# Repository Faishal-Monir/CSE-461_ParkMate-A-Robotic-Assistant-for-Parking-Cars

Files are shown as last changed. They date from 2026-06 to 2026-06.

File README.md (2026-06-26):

# ParkMate - A Robotic Assistant for Parking Cars

## CSE461: Introduction to Robotics [ FALL 2025 ]









ParkMate is a CSE461 robotics project that demonstrates a smart robotic parking assistant.  
The system detects vehicles, opens and closes gates automatically, monitors parking-slot availability, gives visual guidance, supports an EV charging slot, and logs parking status through a dashboard system.

<p align="center">
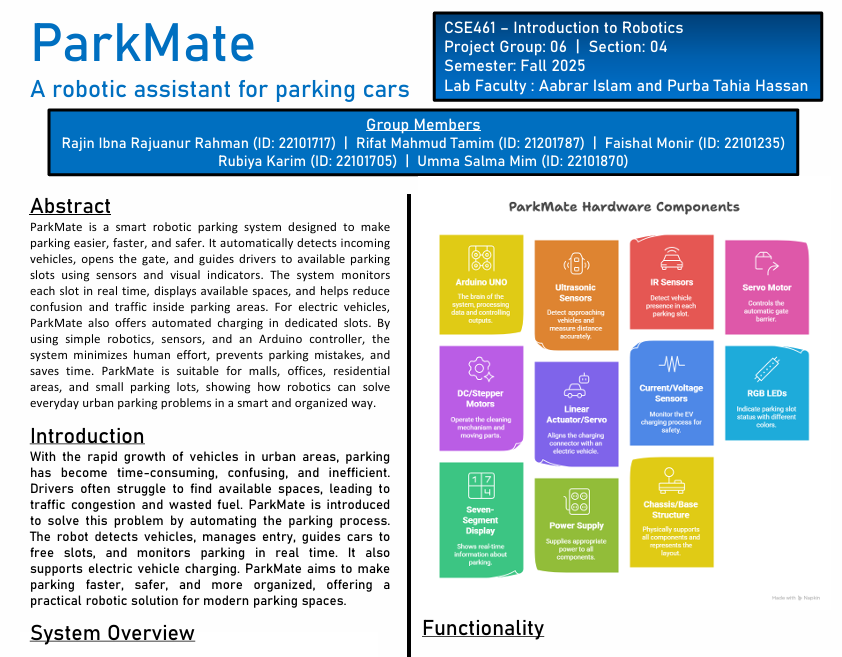
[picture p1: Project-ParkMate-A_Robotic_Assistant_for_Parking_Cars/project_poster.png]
ParkMate Project Poster
  
</p>

<p align="center">
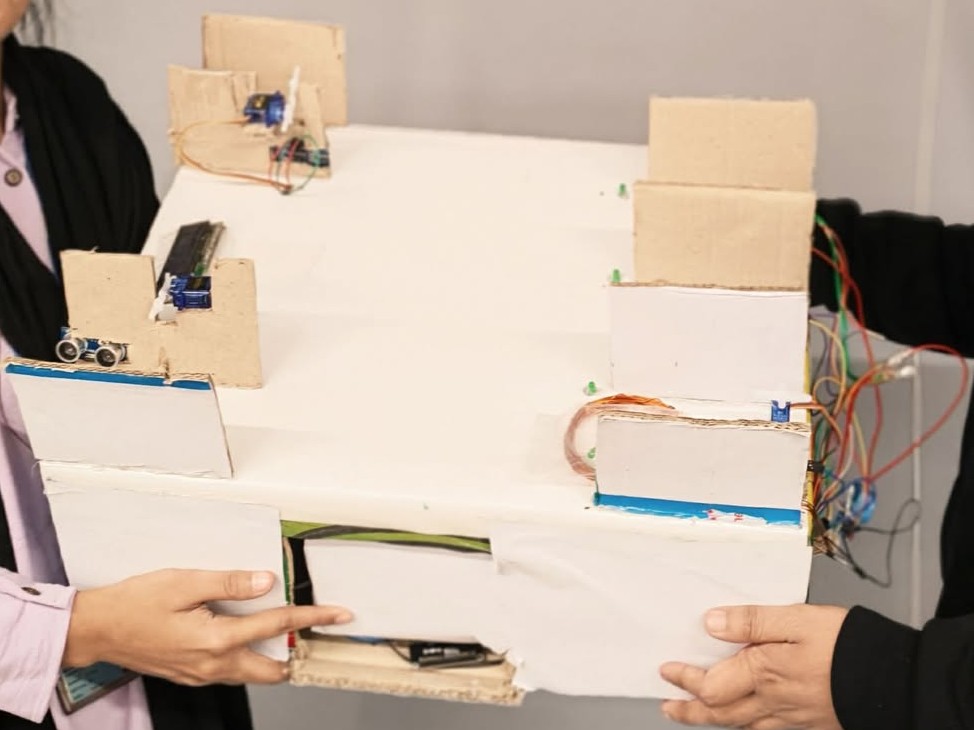
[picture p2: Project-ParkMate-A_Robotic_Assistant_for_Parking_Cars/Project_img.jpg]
ParkMate Hardware Prototype
  
  ParkMate Circuit Diagram
</p>

---

## Table of Contents

- [Repository Highlights](#repository-highlights)
- [Project: ParkMate](#project-parkmate)
- [Course Information](#course-information)
- [Project Overview](#project-overview)
- [System Architecture](#system-architecture)
- [Features](#features)
- [Hardware Components](#hardware-components)
- [Communication Protocols Used](#communication-protocols-used)
- [System Workflow](#system-workflow)
- [Pin / Connection Configuration](#pin--connection-configuration)
- [Required Arduino Libraries](#required-arduino-libraries)
- [Dashboard and Data Logging](#dashboard-and-data-logging)
- [Repository Structure](#repository-structure)
- [Project Files](#project-files)
- [Project Group Members](#project-group-members)
- [Future Work](#future-work)
- [License](#license)

---

## Repository Highlights

- Three-slot smart parking prototype built for **CSE461: Introduction to Robotics**
- Automatic vehicle detection at entry and exit gates using ultrasonic sensors
- Automatic gate opening and closing using servo motors
- Real-time parking-slot detection using IR sensors
- LED-based slot guidance for available and occupied parking spaces
- I2C LCD display for showing car count and available parking slots
- EV charging support for Slot 1 using a relay-based control system
- Automated dashboard/data logging support using ESP8266 and spreadsheet logging
- Slot-cleaning concept using servo motors and a DC motor
- Includes final report, project poster, prototype image, Fritzing circuit diagram, dashboard spreadsheet, and lab files

---

## Project: ParkMate

**ParkMate** is a robotic assistant for parking cars. It is designed to make parking easier, faster, safer, and more organized in small to medium parking areas.

The prototype uses an **Arduino UNO** as the main controller. Sensors detect incoming cars, outgoing cars, and slot occupancy. Based on the sensor readings, the system controls gates, LEDs, display output, EV charging status, and cleaning actuators. The project shows how robotics concepts such as sensing, decision-making, actuation, and automation can solve a real-world parking problem.

---

## Course Information

**Course:** CSE461: Introduction to Robotics  
**Offered:** Fall 2025  
**Pre-requisite:** CSE260, CSE341, CSE360  
**Semester:** Fall 2025  
**Section:** 04  
**Project Group:** 06  

This course introduces robotics by discussing basic laws, architectures, control systems, perceiving techniques, and communication. It also investigates kinematics, motor action, mechanical engineering issues, advanced communication protocols, and uses of AI in robotics.

---

## Project Overview

Parking has become a major problem in busy urban areas because the number of vehicles is increasing while parking space is limited. Drivers often waste time and fuel searching for an empty parking slot. Manual parking systems also depend heavily on human monitoring and do not always provide real-time slot information.

ParkMate solves this problem by automating the main parking tasks. The system detects a vehicle near the gate, opens the gate automatically, checks available slots, guides the driver using LEDs, updates the LCD display, and records parking information in a dashboard log. It also includes EV charging support for one slot and a simple automated slot-cleaning concept.

---

## System Architecture

ParkMate follows a simple robotics architecture with three main layers:

| Layer | Components | Function |
|---|---|---|
| Input Layer | HC-SR04 ultrasonic sensors, IR slot sensors | Detect cars at entry/exit gates and detect slot occupancy |
| Processing Layer | Arduino UNO, ESP8266 | Read sensor data, make decisions, control outputs, send dashboard data |
| Output Layer | Servo motors, DC motor, relay module, LEDs, LCD | Open/close gates, show slot status, control EV charging, display parking data |

---

## Features

- Automatic entry-gate detection and gate control
- Automatic exit-gate detection and gate control
- Three-slot parking availability monitoring
- IR sensor-based car detection for each slot
- LED guidance system for showing available or occupied slots
- LCD display showing total cars and free parking spaces
- Slot 1 EV charging support using a relay-controlled charging system
- ESP8266-based automated dashboard/data transfer concept
- Google Spreadsheet / Excel-based parking log support
- Cleaning mechanism using servo motors for Slot 1 and Slot 2
- DC motor-based cleaning mechanism for Slot 3
- Low-cost and modular prototype design

---

## Hardware Components

| Component | Quantity / Use | Purpose |
|---|---:|---|
| Arduino UNO | 1 | Main microcontroller for decision-making and control |
| ESP8266 | 1 | Sends parking data to the automated dashboard system |
| HC-SR04 Ultrasonic Sensor | 2 | Detects cars at entry and exit gates |
| IR Sensor Module | 3 | Detects whether each parking slot is occupied or empty |
| SG90 Servo Motor | 5 | Controls entry/exit gates and slot-cleaning mechanisms |
| DC Motor | 1 | Used for Slot 3 cleaning actuator |
| 5V Relay Module | 1+ | Controls EV charging / external load switching |
| 16x2 I2C LCD | 1 | Displays car count and available slots |
| RGB / Status LEDs | Multiple | Shows slot availability and system state |
| Resistors, Diode, Transistor | As required | Protects and controls circuit connections |
| Breadboard and Jumper Wires | As required | Builds and connects the prototype circuit |
| 5V / 12V DC Power Supply | 1 | Provides stable power for motors and modules |
| Acrylic / Plywood Base | 1 | Holds the parking-lot prototype structure |

---

## Communication Protocols Used

| Protocol / Method | Used For |
|---|---|
| Digital GPIO | Ultrasonic sensors, IR sensors, LEDs, relay control |
| PWM | Servo motor control and motor actuation |
| I2C | 16x2 LCD display communication |
| UART / Serial-style Communication | Arduino and ESP8266 data transfer concept |
| Wi-Fi / HTTP | ESP8266 dashboard and spreadsheet logging concept |
| Relay Switching | EV charging control and load isolation |

---

## System Workflow

1. The system powers on and initializes the Arduino, sensors, LCD, motors, and dashboard module.
2. The entry ultrasonic sensor checks whether a car is near the entry gate.
3. If a car is detected, the Arduino opens the entry gate using a servo motor.
4. The Arduino reads the three IR sensors to check which parking slots are free.
5. Available slots are shown using LEDs and updated on the LCD display.
6. When a car enters a slot, the related IR sensor changes its reading.
7. The system updates the slot status from available to occupied.
8. Slot 1 supports EV charging through a relay-controlled charging system.
9. Parking data can be transferred to the dashboard/log file using the ESP8266 module.
10. The exit ultrasonic sensor detects outgoing cars and opens the exit gate.
11. The LCD and dashboard log are updated after every parking status change.

---

## Pin / Connection Configuration

The exact wiring is documented in the included Fritzing file:

```text
Project-ParkMate-A_Robotic_Assistant_for_Parking_Cars/461project circuit diagram.fzz
```

Main prototype connections:

| Module | Arduino / Circuit Connection |
|---|---|
| Entry HC-SR04 Sensor | Digital trigger and echo pins |
| Exit HC-SR04 Sensor | Digital trigger and echo pins |
| Slot 1 IR Sensor | Digital input pin |
| Slot 2 IR Sensor | Digital input pin |
| Slot 3 IR Sensor | Digital input pin |
| Entry Gate Servo | PWM-capable digital pin |
| Exit Gate Servo | PWM-capable digital pin |
| Slot 1 Cleaning Servo | PWM-capable digital pin |
| Slot 2 Cleaning Servo | PWM-capable digital pin |
| Slot 3 DC Motor | Relay / transistor driver circuit |
| EV Charging Relay | Relay signal control pin |
| Status LEDs | Digital output pins through resistors |
| I2C LCD SDA | Arduino A4 |
| I2C LCD SCL | Arduino A5 |
| ESP8266 | Serial / data communication pins with common ground |
| Power Modules | 5V / 12V supply with common ground |

> Before uploading final code, verify the exact pin numbers from the Fritzing circuit diagram and match them with the Arduino sketch.

---

## Required Arduino Libraries

Install the required libraries in Arduino IDE depending on the modules used in the final sketch:

```cpp
#include <Wire.h>
#include <LiquidCrystal_I2C.h>
#include <Servo.h>
```

For ESP8266 dashboard or internet-based logging, the ESP8266 board package and Wi-Fi libraries may also be required:

```cpp
#include <ESP8266WiFi.h>
#include <ESP8266HTTPClient.h>
```

---

## Dashboard and Data Logging

The project folder includes:

```text
SmartParkingLog.xlsx
```

This spreadsheet contains a dashboard and a parking log. The log tracks values such as:

- Timestamp
- Available Slots
- Occupied Slots
- Slot 1 EV status
- Slot 2 status
- Slot 3 status
- EV Relay Status

This supports the automated dashboard concept mentioned in the project report.

---

## Repository Structure

```text
.
├── README.md
├── LICENSE
├── LAB-1/
│   ├── CSE461 Lab Report Template.pdf
│   ├── CSE461 Lab Worksheet 1.pdf
│   ├── LAB-1 CODE.pdf
│   ├── TASK-3/TASK-3.ino
│   └── lab images
├── LAB-2/
│   ├── CSE461 Lab Report-2.pdf
│   ├── CSE461 Lab Worksheet 2.pdf
│   ├── Setting up Raspberry PI.pdf
│   ├── Lab-2_Evaluation/Lab-2_Evaluation.ino
│   └── lab images
├── LAB-3/
│   ├── CSE461 Lab Report-3 .pdf
│   ├── CSE461 Lab Worksheet 3.pdf
│   ├── Setting up Arduino IDE in Raspberry PI.pdf
│   ├── Lab-3_Evaluation/Lab-3_Evaluation.ino
│   └── lab images
├── LAB-4/
│   ├── CSE461 Lab Report-4.pdf
│   ├── CSE461 Lab Worksheet 4.pdf
│   ├── CSE461 Lab-4 Report.pdf
│   └── lab images
├── LAB-5/
│   ├── CSE461 Lab Report-5.pdf
│   ├── CSE461 Lab Worksheet 5.pdf
│   ├── Black and White Zone.pdf
│   ├── labcode.py
│   └── lab images
├── LAB-6/
│   ├── CSE461 Lab Worksheet 6.pdf
│   ├── evaluation code.py
│   └── lab images
├── LAB-7/
│   ├── CSE461 Lab Worksheet 7.pdf
│   ├── LAB-7 CODE.pdf
│   └── lab images
├── LAB-Evaluation/
│   ├── CSE461 Lab Worksheet 8.docx.pdf
│   ├── _CSE461 Lab Report-8 Template.pdf
│   ├── LAb evaluation_bb.jpg
│   └── evaluation images
└── Project-ParkMate-A_Robotic_Assistant_for_Parking_Cars/
    ├── 461project circuit diagram.fzz
    ├── 461project circuit diagram_bb.jpg
    ├── F25_CSE461_4_6_1.pdf
    ├── Park-Mate-Group-06.pdf
    ├── Project_img.jpg
    ├── project_poster.png
    └── SmartParkingLog.xlsx
```

---

## Project Files

| File | Description |
|---|---|
| `Project-ParkMate-A_Robotic_Assistant_for_Parking_Cars/F25_CSE461_4_6_1.pdf` | Final lab project report |
| `Project-ParkMate-A_Robotic_Assistant_for_Parking_Cars/Park-Mate-Group-06.pdf` | Project poster / one-page presentation |
| `Project-ParkMate-A_Robotic_Assistant_for_Parking_Cars/project_poster.png` | Poster image used in this README |
| `Project-ParkMate-A_Robotic_Assistant_for_Parking_Cars/Project_img.jpg` | Hardware prototype image |
| `Project-ParkMate-A_Robotic_Assistant_for_Parking_Cars/461project circuit diagram_bb.jpg` | Breadboard circuit diagram image |
| `Project-ParkMate-A_Robotic_Assistant_for_Parking_Cars/461project circuit diagram.fzz` | Editable Fritzing circuit file |
| `Project-ParkMate-A_Robotic_Assistant_for_Parking_Cars/SmartParkingLog.xlsx` | Smart parking dashboard and data log spreadsheet |
| `LAB-1` to `LAB-Evaluation` | Course lab reports, worksheets, codes, and hardware images |
| `LICENSE` | MIT license file |

---

## Project Group Members

[Rifat Mahmud Tamim](https://github.com/RIFAT-MAHMUD-TAMIM-00) |[Rajin Ibna Rajuanur Rahman](https://github.com/rajin50) | [Umma Salma Mim](https://github.com/ummasalmamim) | [Rubiya Karim](https://www.facebook.com/rubaiya.karim.1) | [Faishal Monir](https://github.com/Faishal-Monir)

---

## Future Work

- Add a more accurate exit sensor system for real-time car counting
- Add a larger display sign for showing specific available slots
- Improve wireless monitoring for remote parking status checking
- Expand the prototype from three slots to a larger parking system
- Improve EV charging safety for real-world implementation
- Add stronger mechanical protection and better motor drivers
- Improve sensor calibration for different lighting and surface conditions

---

## License

This repository is released under the **MIT License**.

This project was developed for academic purposes as part of **CSE461: Introduction to Robotics** at **BRAC University**.

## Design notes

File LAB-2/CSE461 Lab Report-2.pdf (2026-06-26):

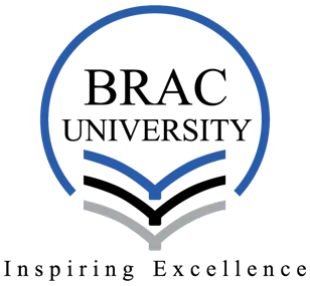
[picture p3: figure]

### CSE461

Introduction to Robotics Lab

Lab No. : 02
Group : 06
Section : 04
Semester : Fall_2025

Group members :

Rifat Mahmud Tamim | 21201787
Faishal Monir | 22101235
Rubiya Karim | 22101705
Rajin Ibna Rajuanur Rahman | 22101717
Umma Salma Mim | 22101870

Submitted Date: 05-11-2025 Submitted to - Aabrar Islam and Purba Tahia Hassan

1. Objectives: The aim of the current experiment is to create and construct a simple circuit using Raspberry Pi, which would switch an LED. When the switch is released, the LED will go off and when it is pressed, it will go on. The given task is intended to aid the comprehension of the fundamental application of the GPIO pins, input and output control and communication between the hardware and software components using Python.

### 2. Equipments:

- Raspberry PI
- LED (Light Emitting Diode)
- Push-button switch
- Resistor (220Ω for LED)
- Breadboard
- Jumper wires

### 3. Experimental Setup:

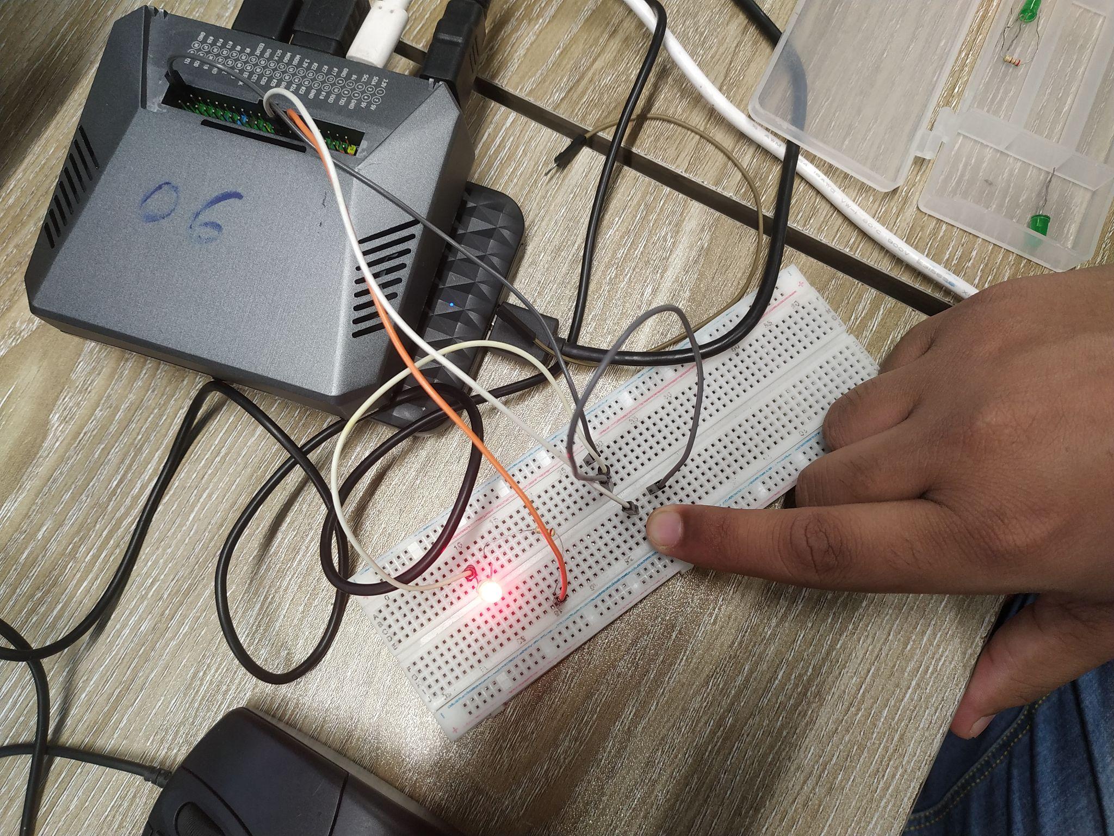
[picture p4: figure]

The LED is connected to the GPIO pin 18 together with a 220 ohm resistor, and the switch is attached to the GPIO pin 23. Pressing the switch will make the LED turn ON, and of course, releasing the switch will turn the LED OFF. The circuit is driven with the help of a python program that measures the input of the switch with the help of the GPIO pins.

Circuit Diagram:

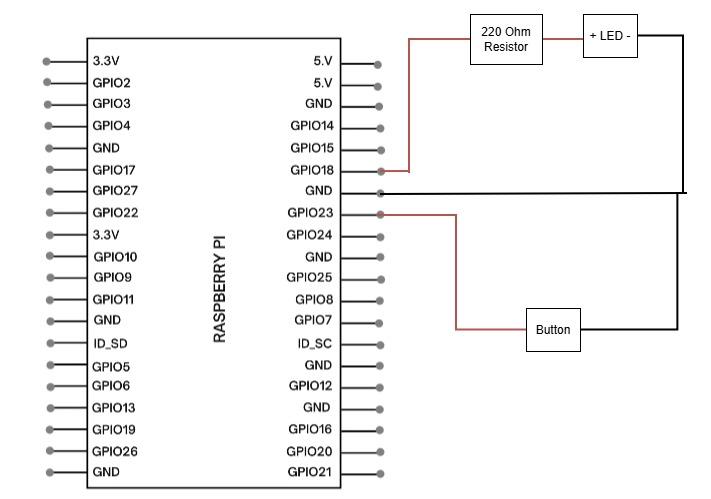
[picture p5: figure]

### 4. Code:

# Enter Code Here

from gpiozero import LED, Button import time

led = LED(18)
button = Button(23)

while True:
if button.is_pressed:
led.on()
print("Switch pressed")
else:
led.off()
print("Not pressed")
time.sleep(0.5)

### 5. Results (Output of the experiment): The experiment was completed successfully. The

press of the push-button switch would change the state of the LED to ON and the release would change it to OFF. The python code was functional and displayed messages such as Switch pressed and Not pressed at the terminal. This proved that the Raspberry Pi was able to receive the button input and output the LED. The circuit was useful to illustrate the simple application of the GPIO pins to digital input and output.

Button State | Output | Terminal
Pressed | LED ON | Switch pressed
Released | LED OFF | Not pressed

### 6. Discussions/Answers:

This experiment served to learn how a Raspberry Pi can be used to turn on and off an LED with the help of a push-button switch with the help of the GPIO pins. The findings indicated that the LED was able to read the button press, and thus had elementary control of digital input and output. Certain difficulties were making sure that connections were correct on the breadboard and the correct use of the GPIO pins in the code. Solutions were found by making sure the circuit is well checked and that the pin numbers of the Python program were well checked. In general, the task was useful as it gave us hands-on experience with interaction between hardware and software, the lesson about the use of resistors to safeguard the components and better knowledge of Python-based programming with the use of the GPIO on real-world projects. The experiment supported the idea of observing inputs and regulating outputs in embedded systems in an effective way.

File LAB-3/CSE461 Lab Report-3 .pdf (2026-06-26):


### CSE461

Introduction to Robotics Lab

Lab No. : 03
Group : 06
Section : 04
Semester : Fall_2025

Group members :

Rifat Mahmud Tamim | 21201787
Faishal Monir | 22101235
Rubiya Karim | 22101705
Rajin Ibna Rajuanur Rahman | 22101717
Umma Salma Mim | 22101870

Submitted Date: 12-11-2025 Submitted to - Aabrar Islam and Purba Tahia Hassan

### 1. Objectives: The objective of this lab is to understand the basic functionality of the

Raspberry Pi microcontroller and learn how to connect input and output devices using its pins. Specifically, the lab seeks to measure distance with an ultrasonic sensor (HC-SR04) and control the LED depending on the distance measured. Through this experiment, students will have a hands-on experience in circuit-making, interfacing sensors, Python programming on the Raspberry Pi, and implementing simple real-time control logic.

### 2. Equipment:

- Raspberry PI
- LED (Light Emitting Diode)
- Ultrasonic Sensor (HC-SR04)
- Resistor (220Ω for LED)
- Breadboard
- Jumper wires
- Monitor, keyboard, and mouse (for Raspberry Pi setup)

### 3. Experimental Setup:

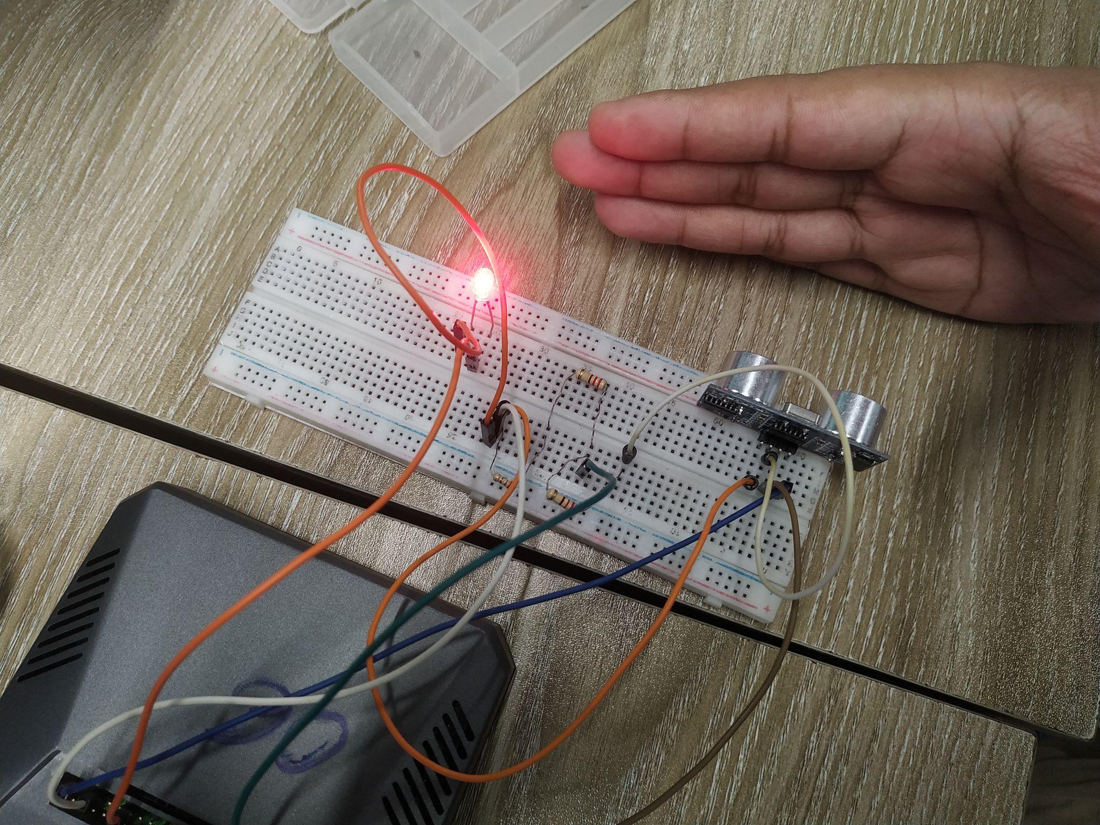
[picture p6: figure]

The ultrasonic sensor (HC-SR04) is connected to the Raspberry Pi board using the pin setup, with the TRIG pin connected to pin 21. The ECHO pin is connected to pin 20 using a voltage divider circuit, which is constructed by using 220 Ohm resistors so that the signal does not exceed 3.3V. The VCC pin of the sensor is connected with the 5V power pin, while the GND pin is connected with the ground of the Raspberry Pi.

An LED is connected in series with a 220 ohm resistor to control the current and is connected to pin 18 of the GPIO. The LED will be used as an indicator that is turned ON if the measured distance is less than 5cm.

The control of the circuit is done using a Python program running on the Raspberry Pi. The program is continuously used for sending trigger signals to the ultrasonic sensor to measure the distance by calculating the time delay between the sent ultrasonic waves and the received ultrasonic waves. If the calculated distance is less than 5 cm, then the program turns ON the LED; otherwise, it turns OFF the LED.

Circuit Diagram:

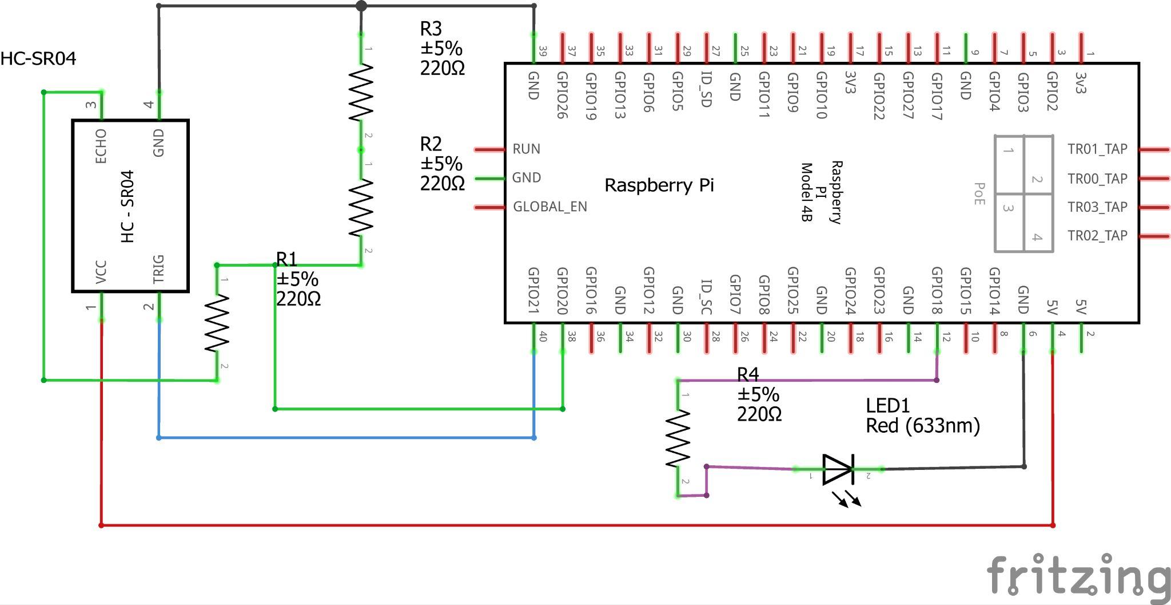
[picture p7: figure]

### 4. Code:

import RPi.GPIO as GPIO
from gpiozero import LED, Button import time

GPIO.setmode(GPIO.BCM)
TRIG = 21 # GPIO21
ECHO = 20 # GPIO20
led = LED(18)

GPIO.setup(TRIG, GPIO.OUT) GPIO.setup(ECHO, GPIO.IN)

def distance():
GPIO.output(TRIG, False)
time.sleep(0.5)
GPIO.output(TRIG, True)
time.sleep(0.00001)
GPIO.output(TRIG, False)
pulse_start = time.time()
while GPIO.input(ECHO) == 0: pulse_start = time.time()
while GPIO.input(ECHO) == 1: pulse_end = time.time()

pulse_duration = pulse_end - pulse_start distance_val = pulse_duration * ((343 * 100) / 2) distance_val = round(distance_val, 2)
return distance_val

while True:
dis = distance()
print(dis)
if dis < 5:
led.on()
else:
led.off()

GPIO.cleanup()

### 5. Results (Output of the experiment): The experiment was done successfully. The

ultrasonic sensor detected the distance between the ultrasonic sensor and an obstacle in real-time, and the LED acted based on the value of the distance. When the object was placed nearer than 5 cm, the LED switched ON, and when the object was moved to a farther distance urging the LED switched OFF.
During execution, the Python program was continuously sending and receiving the time values and calculating the distance from the formula. For example, the distance detected by the sensor can be read during the testing: 3.45, 4.87, and 6.12 were displayed. When the distance fell below the 5 cm mark, the LED turned on, and we got the successful result of reading the ultrasonic sensor in the Raspberry Pi and controlling the LED output via the pins of the GPIO.
Measured Distance (cm) | LED Output
3.45 | LED ON
4.90 | LED ON
6.12 | LED OFF

### 6. Discussions/Answers:

This experiment showed how a Raspberry Pi can be used to measure distance with an ultrasonic sensor and turn an LED on/off based on the measured values through the Raspberry Pi's pins. The results showed that the Raspberry Pi successfully received input signals from the ultrasonic sensor and calculated distance accurately in real time. The LED light turned on when the measured distance was less than 5 cm and off when it was more than 5 cm. So we can ensure that the input device and output device work properly. We faced some issues that we faced during the experiment. For examplethere were some inaccurate readings during the experiment because of the wrong wiring or placement of the register. Overall, the experiment was effective and enhanced learning of Python-based programming for GPIO control, HC-SR04 ultrasonic sensor for distance measurement.

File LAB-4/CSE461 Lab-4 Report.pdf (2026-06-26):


### CSE461

Introduction to Robotics Lab

Lab No. : 04
Group : 06
Section : 04
Semester : Fall_2025

Group members :

Rifat Mahmud Tamim | 21201787
Faishal Monir | 22101235
Rubiya Karim | 22101705
Rajin Ibna Rajuanur Rahman | 22101717
Umma Salma Mim | 22101870

Submitted Date: 03-12-2025 Submitted to - Aabrar Islam and Purba Tahia Hassan

Objectives:

This lab aims at learning how to interface two microcontrollers (Arduino Uno and Raspberry Pi) through the UART communication protocol. In this experiment, the Arduino reads the value of the light sensor of an LDR and transmits it to the Raspberry Pi. The Raspberry Pi gets the data and uses it to switch on an LED accordingly by brightening or dimming it. In this assignment, the students acquire knowledge in sensor reading, UART communication, voltage-level shifting, Python coding, and the use of PWM to drive an output device.

### 2. Equipment:

- Arduino Uno
- Raspberry Pi 4
- LED (Light Emitting Diode)
- LDR sensor
- 220Ω resistors
- Breadboard
- Jumper wires
- Voltage divider components

### 3. Experimental Setup:

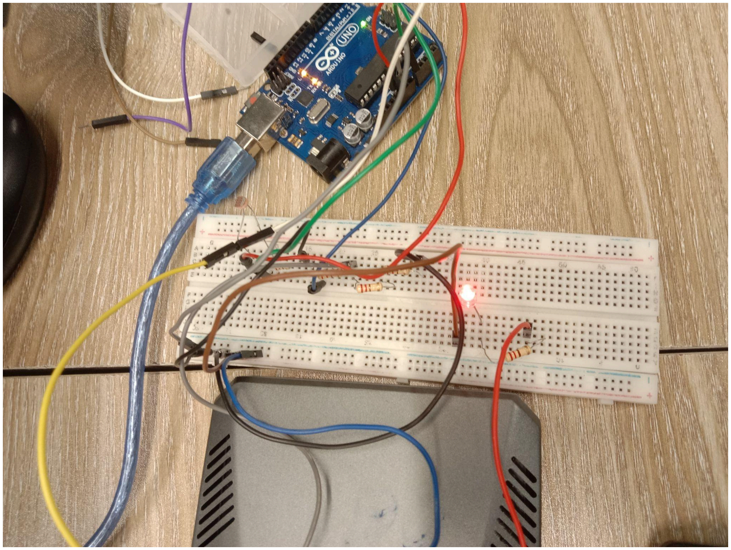
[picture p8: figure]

The voltage divider connects the sensor of LDR with the Arduino Uno. The LDR is connected to analog pin A0 and 5V on its one end. The resistor is connected between A0 and GND. The Arduino will read the value presented by the LDR and send the value to the Raspberry Pi using UART protocol.

A resistor of 220 Ohms joins LED and the Raspberry Pi pin onGPIO 18. To control the brightness of the LED, the PWM is employed.

The TX pin in the Raspberry Pi (GPIO14) is connected to the RX pin in the Arduino in the UART. A voltage divider is required to reduce the 5V output to 3.3 V to connect the Arduino TX pin and Raspberry Pi RX pin (GPIO15). There is one similarity between the two devices.

A Python script is run on the Raspberry Pi and reads the serial data sent by the Arduino. LDR value changes according to the intensity of the light; therefore, the Raspberry Pi controls the intensity of LED light. Light is dim in the case of the LED and dark in the case of the LED.

Circuit Diagram:

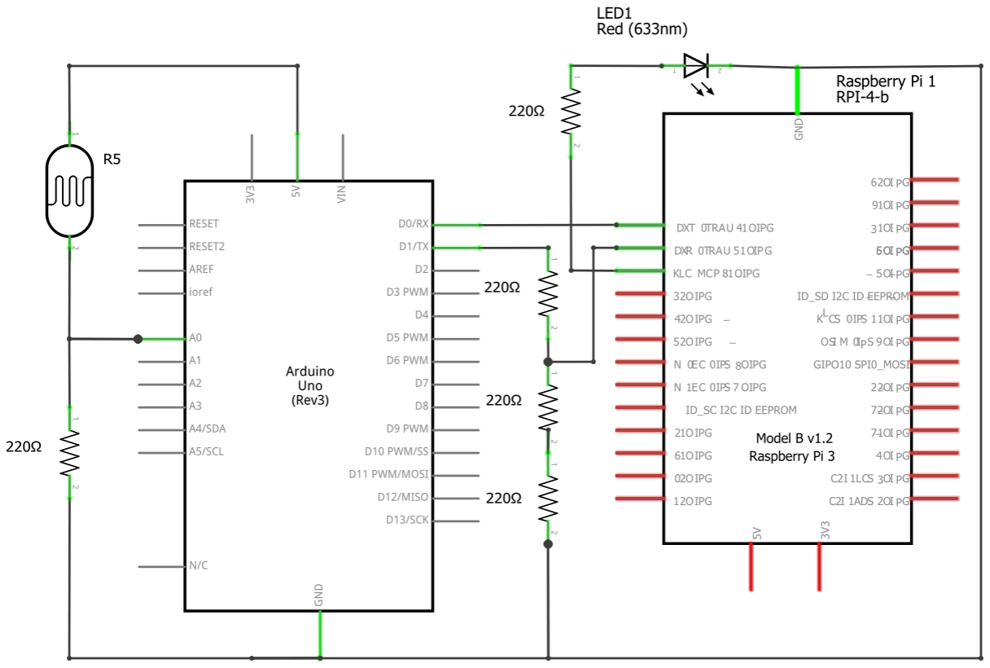
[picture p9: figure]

Fig. Arduino and Raspberry PI interfacing Schematic Diagram

### 4. Code:

❖ Arduino Code:

int ldrPin = A0;
int ldrValue = 0;

void setup() {
Serial.begin(9600);
}

void loop() {
ldrValue = analogRead(ldrPin); // Read LDR value (0–1023) Serial.println(ldrValue); // Send value to Raspberry Pi delay(100);
}

❖ Raspberry Pi Code:

import serial
import RPi.GPIO as GPIO
import time

# Setup

GPIO.setmode(GPIO.BCM)
led_pin = 18
GPIO.setup(led_pin, GPIO.OUT)

# Initialize PWM

pwm_led = GPIO.PWM(led_pin, 1000) # 1 kHz frequency pwm_led.start(0)

# Connect to Arduino

arduino = serial.Serial('/dev/ttyACM0', 9600, timeout=1) time.sleep(2)
norm = 2.5

try:
while True:
data = arduino.readline().decode('utf-8').strip()
if data.isdigit():
ldr_value = int(data)
brightness = ((1-(ldr_value / 1023)) ** norm) * 100 Brightness = max(0, min(brightness, 100)) pwm_led.ChangeDutyCycle(brightness)
print(f"LDR: {ldr_value}, LED Brightness: {brightness:.1f}%")

except KeyboardInterrupt:
print("Exiting...")
finally:
pwm_led.stop()
GPIO.cleanup()
arduino.close()

### 5. Results (Output of the experiment):

The experiment was successfully carried out. The Arduino had the capability of reading the LDR sensor values and transmitting them to the Raspberry Pi via UART. Raspberry Pi was able to receive the values and regulate the brightness of the LED with the help of PWM. In a high light level, the LDR value was high and a dim light was emitted. The brightness of the LED was greater when the level of light was low. Other readings that were shown by the serial monitor included: 180, 320, 850, etc. These values indicated the variation in the intensity of light during testing.

Light Condition | LDR Value | LED Output
Bright light | High | Dim
Medium Light | Mid | Medium
Dark light | Low | Bright

### 6. Discussions/Answers:

In this experiment, it was shown that a two microcontroller communication could be achieved through UART. Arduino had capacity to send sensor data to the Raspberry Pi and the Pi had capability to control one LED on the received data. The experiment also demonstrated the importance of a voltage divider in the process of connecting 5V Arduino to a 3.3V Raspberry Pi.

There were certain issues in the experiment such as TX/RX wiring was not done properly and problems of serial connection in case the UART pins were connected before uploading the code. This was checked after upload verification of the wiring and connection of UART. Overall, this experiment provided an insight into the principles of the UART communication, the way of reading analog sensors, controlling the PWM output, and how both of the devices can be integrated into a basic real-time system.

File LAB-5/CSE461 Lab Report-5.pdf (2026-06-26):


### CSE461

Introduction to Robotics Lab

Lab No. : 05
Group : 06
Section : 04
Semester : Fall_2025

Group members :

Rifat Mahmud Tamim | 21201787
Faishal Monir | 22101235
Rubiya Karim | 22101705
Rajin Ibna Rajuanur Rahman | 22101717
Umma Salma Mim | 22101870

Submitted Date: 03-12-2025 Submitted to - Aabrar Islam and Purba Tahia Hassan

### 1. Objectives: The objective of this lab is to interface an Arduino Uno and Raspberry Pi

using the UART protocol to enable real-time transfer of IR sensor data. The lab aims to read analogue values from a 6-array IR sensor, send the processed output to the Raspberry Pi, and display the sensor status on an I2C LCD. Additionally, the experiment focuses on implementing a simple LED-based indication system on the Raspberry Pi and ensuring proper voltage-level compatibility between both devices. Through this activity, we developed skills in microcontroller communication, circuit design, and hardware software integration.

### 2. Equipment:

- Arduino Uno R3
- Raspberry Pi 4
- Analogue 6-array IR sensor
- I2C LCD Display (16x2)
- Resistor (220Ω)
- Breadboard
- Jumper wires
- LED

### 3. Experimental Setup:

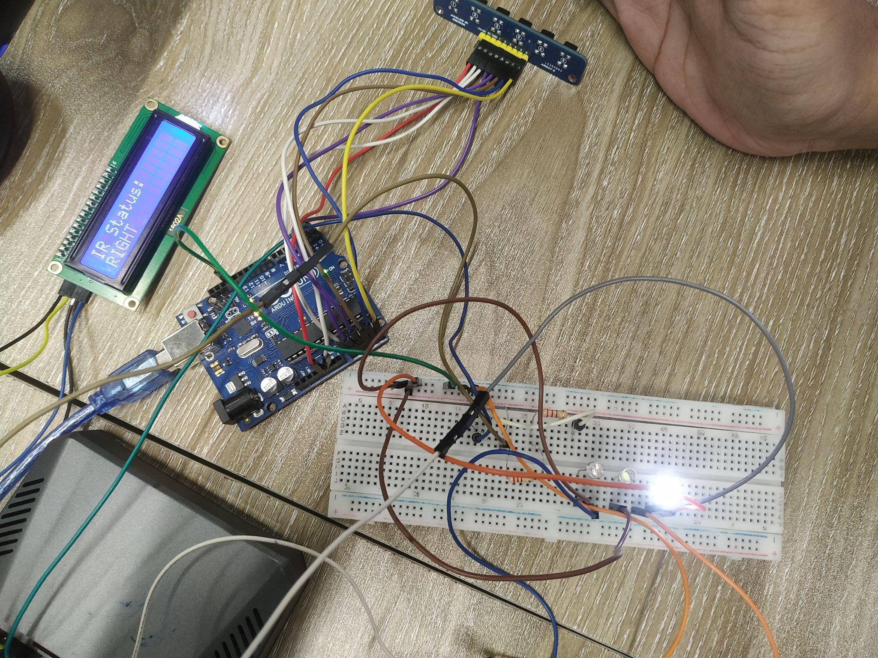
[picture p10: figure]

In this experiment, the Arduino Uno was used to read values from the 6-array IR sensor and decide whether the system should display LEFT, RIGHT, or FORWARD. The Arduino sent these messages to the Raspberry Pi using UART communication.

On the Raspberry Pi, three LEDs were connected to GPIO pins 13, 19, and 26. These LEDs were used to show the direction sent by the Arduino. An I2C 16×2 LCD was also connected to the Raspberry Pi to display the sensor status. This setup shows how the Arduino and Raspberry Pi communicate with each other, and how the Raspberry Pi controls LEDs and an LCD based on the received sensor data.

Circuit Diagram:

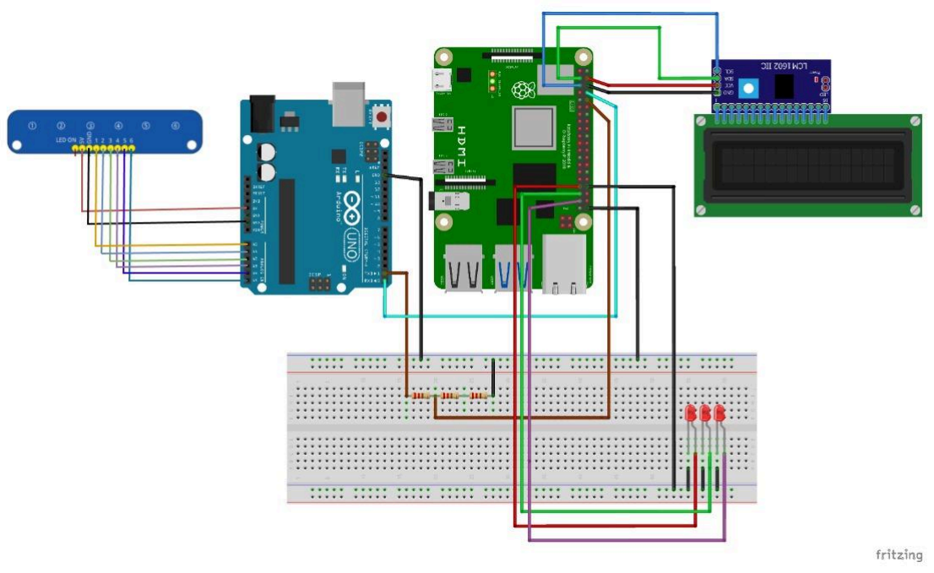
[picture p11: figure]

### 4. Code:

❖ Arduino Code:

#define NUM_SENSORS 6

int sensorPins[NUM_SENSORS] = {A0, A1, A2, A3, A4, A5}; int sensorValues[NUM_SENSORS];

void setup() {
Serial.begin(9600);
for (int i = 0; i < NUM_SENSORS; i++) { pinMode(sensorPins[i], INPUT);
}
}

void loop() {
for (int i = 0; i < NUM_SENSORS; i++) { sensorValues[i] = analogRead(sensorPins[i]); }

int threshold = 500;
int binary[NUM_SENSORS];
for (int i = 0; i < NUM_SENSORS; i++) {
binary[i] = (sensorValues[i] > threshold) ? 0 : 1;

}

if (binary[0] == 1 && binary[1] == 1 && binary[2] == 1 && binary[3] == 1 && binary[4] == 1 && binary[5] == 1) {
Serial.println("STOP");
}
else if (binary[0] == 0 && binary[1] == 0 && binary[2] == 0 && binary[3] == 0 && binary[4] == 0 && binary[5] == 0) {
Serial.println("FORWARD");
}
else if (binary[0] == 0 || binary[1] == 0) { Serial.println("LEFT");
}
else if (binary[4] == 0 || binary[5] == 0) { Serial.println("RIGHT");
}
else {
Serial.println("UNCERTAIN"); }

delay(200);
}

❖ Raspberry Pi Code:

import serial
from rpi_lcd import LCD
from time import sleep
from gpiozero import LED, Button import time

lcd = LCD()

led1 = LED(13)
led2 = LED(19)
led3 = LED(26)

ser = serial.Serial('/dev/ttyS0', 9600, timeout=1)

try:
while True:
if ser.in_waiting > 0:

line = ser.readline().decode('utf-8', errors='ignore').strip()

lcd.clear()
lcd.text("IR Status: ", 1) lcd.text(line, 2)

if line=="LEFT":
led1.on()
led2.off()
led3.off()
elif line=="RIGHT":
led1.off()
led2.off()
led3.on()
elif line=="FORWARD":
led1.on()
led2.on()
led3.on()
else:
led1.off()
led2.off()
led3.off()

except KeyboardInterrupt:
lcd.clear()
ser.close()
print("Program terminated")

### 5. Results (Output of the experiment):

The experiment was completed successfully. The Arduino correctly detected the IR sensor readings and sent the direction messages (LEFT, RIGHT, or FORWARD) to the Raspberry Pi through UART. The Raspberry Pi then displayed the received message on the I2C LCD and controlled the LEDs based on the direction.

During execution, the Python program continuously read the incoming serial messages and updated the LCD and LEDs in real time. For example, when the sensor output indicated LEFT, only the left LED turned ON, when RIGHT was received, the right LED turned ON. For FORWARD, all LEDs turned ON together. For any message outside these three (such as STOP or UNCERTAIN), all LEDs remained OFF.

Sensor Status | LED Output
Right | Right LED ON
Left | Left LED ON
Forward | All LEDs ON

These results confirm that the Raspberry Pi successfully received the sensor data from the Arduino, displayed the status on the LCD, and controlled the LEDs correctly through its GPIO pins.

### 6. Discussions/Answers:

This experiment demonstrated how the Raspberry Pi can receive direction messages from an Arduino using the UART protocol and then control LEDs and an LCD screen based on the received data. The results showed that the Raspberry Pi successfully read the IR sensor status sent by the Arduino and updated the I2C LCD in real time. The LEDs responded correctly according to the message: the left LED turned on for LEFT, the right LED turned on for RIGHT, and all LEDs turned on for FORWARD, while they remained off for any unknown or uncertain message. This confirms that both the input signals from the Arduino and the output control on the Raspberry Pi were functioning properly. During the experiment, some issues were encountered, such as inconsistent serial readings when the wires were loose or the UART connection was not properly grounded. After fixing the wiring, the communication became stable. Overall, the experiment was effective and helped in understanding UART communication, GPIO control, and Python programming on the Raspberry Pi, along with how sensor data can be used to drive real-time hardware actions.

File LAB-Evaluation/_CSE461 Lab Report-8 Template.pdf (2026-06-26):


### CSE461

Introduction to Robotics Lab

### Lab Evaluation Report

Group : 06
Section : 04
Semester : Fall_2025

Group members :

Rifat Mahmud Tamim | 21201787
Faishal Monir | 22101235
Rubiya Karim | 22101705
Rajin Ibna Rajuanur Rahman | 22101717
Umma Salma Mim | 22101870

Submitted Date: 24-12-2025 Submitted to - Aabrar Islam and Purba Tahia Hassan

### 1. Objectives: The main objective of this scenario was to design and implement a system

with day/night control using basic robotic components called the Smart Pet Feeder. The system is instructed to release food only during the daytime when enough light is detected using an LDR sensor, and a manual trigger button is pressed.
Additionally, our main goal was learning about the integration of sensors (LDR, button), actuators (servo motor), and output devices (LED and LCD) with a microcontroller to form a simple real-life automated solution with proper condition checking and status indication.

### 2. Equipment:

- Arduino board
- Servo Motor
- LDR
- LCD Display
- Push Button
- LED

### 3. Experimental Setup:

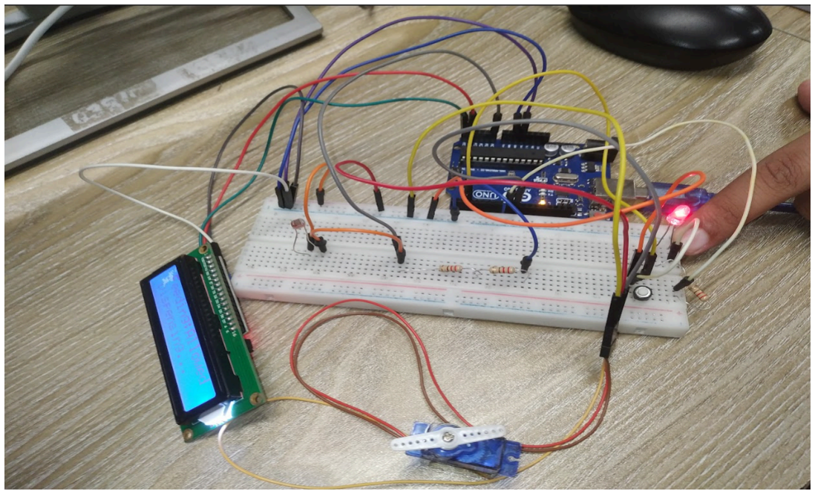
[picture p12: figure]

In this simple experiment, the servo motor was connected to the Audino using the pins VCC, GND and pin D(9). LCD was connected using the pins vcc,gnd [(SDA→A4)(SCL→A5)]. Similarly, LDR was connected to the vcc and the other pin to A0. Likewise, according to the circuit below all the other components were connected.

Circuit Diagram:
- Lab Approved Circuit: G-Drive (https://drive.google.com/file/d/1H2pdIB_rGZgYF5tcLVKpZHNlaM1qmPgQ/view?usp=sharing)
- Digital copy of the circuit: G-drive (https://drive.google.com/file/d/1QC02QFPitFar_tGe53Ox9nDQyFR9AJ4e/view?usp=sharing)

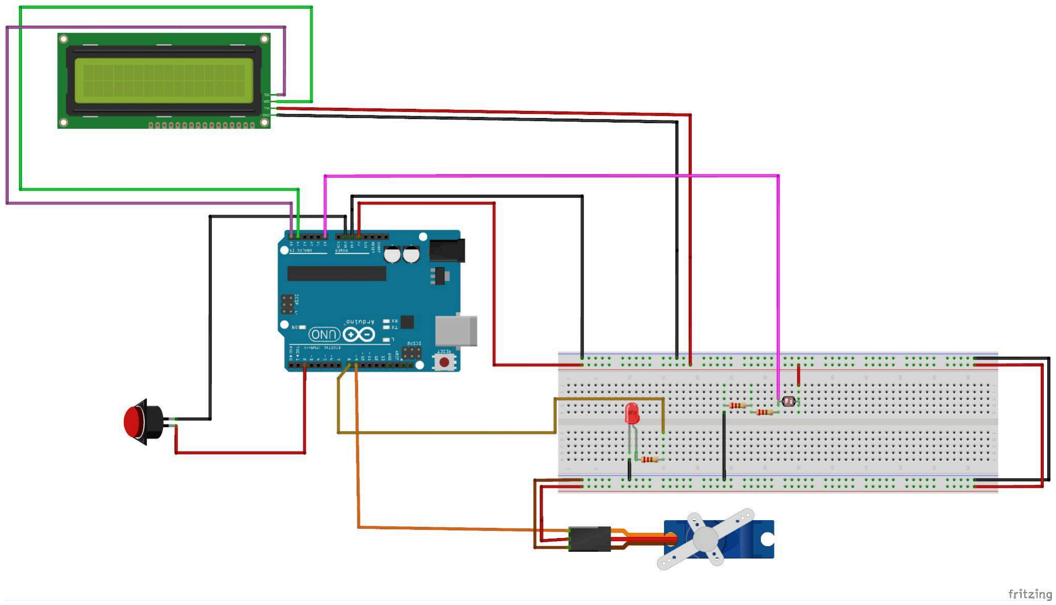
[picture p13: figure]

### 4. Code:

#include <Wire.h>

#include <LiquidCrystal_I2C.h> #include <Servo.h>

#define LDR_PIN A0

#define BUTTON_PIN 2

#define LED_PIN 8

#define SERVO_PIN 9

LiquidCrystal_I2C lcd(0x27, 16, 2); Servo feederServo;

int lightThreshold = 100;
int servoRestPos = 0;
int servoFeedPos = 90;

void setup() {
Serial.begin(9600);
Serial.println("Smart Pet Feeder System Started");

pinMode(LED_PIN, OUTPUT);
pinMode(BUTTON_PIN, INPUT_PULLUP);

feederServo.attach(SERVO_PIN); feederServo.write(servoRestPos);
Serial.println("Servo initialized at original position");

lcd.init();
lcd.backlight();

lcd.clear();
lcd.setCursor(0, 0);
lcd.print("Smart Pet Feeder");

delay(2000);
lcd.clear();
}

void loop() {
int ldrValue = analogRead(LDR_PIN);
int buttonState = digitalRead(BUTTON_PIN);

Serial.print("LDR Value: "); Serial.println(ldrValue);

if (ldrValue > lightThreshold) { Serial.println("Status: Daytime detected"); Serial.println("Feeding Status: Allowed");

digitalWrite(LED_PIN, HIGH);

lcd.setCursor(0, 0);
lcd.print("Feeding:Allowed");

lcd.setCursor(0, 1);
lcd.print("LDR:");
lcd.print(ldrValue);
lcd.print(" | ");
| if (buttonState == LOW) { Serial.println("Button Pressed"); Serial.println("Action: Dispensing food");
| lcd.clear(); lcd.setCursor(0, 0); lcd.print("Feeding:Allowed"); lcd.setCursor(0, 1); lcd.print("Dispensing...");
| feederServo.write(servoFeedPos); Serial.println("Servo rotated to 90 degrees");
| delay(5000);
| feederServo.write(servoRestPos); Serial.println("Servo returned to original

position");

| delay(500); }
| else { Serial.println("Button not pressed"); }

}

else {
Serial.println("Status: Nighttime or Darkness detected"); Serial.println("Feeding Status: Not Allowed");

digitalWrite(LED_PIN, LOW);

lcd.setCursor(0, 0);
lcd.print("Feeding:Not-Allowed");

lcd.setCursor(0, 1);
lcd.print("LDR:");

lcd.print(ldrValue);
lcd.print(" Too Dark");
}

Serial.println("---------------------------"); delay(300);
}

### 5. Results (Output of the experiment):

After the successful implementation of the experiment, the smart pet feeder system functioned according to the defined conditions. The ambient light levels were continuously monitored using an LDR sensor to decide whether feeding would be permitted or not. When the intensity of light crossed the predefined value (daytime), the system allowed for feeding and turned the LED ON as an indication of permission to feed.

When the push button is pressed during the daytime, the servo motor rotates by 90 degrees for a short time period (1-2 seconds) to simulate food dispensing and returns to its original position. At this action, the LCD message "Dispensing…" appears.

If the environment was dark (nighttime), the feeding was not allowed, regardless of the button pressing, the LED was still OFF, and the LCD showed "Feeding: Not allowed".

Light Condition | Button Pressed | Servo Action | LED Status | LCD Display
Bright (Day) | Yes | Rotates 90° (Food Dispensed) | ON | Dispensing…
Bright (Day) | No | No movement | ON | Feeding: Allowed
Dark (Night) | Yes/No | No movement | OFF | Feeding: Not allowed

### 6. Discussions/Answers:

From this lab, we got practical knowledge in designing a condition-based automated system using sensors and actuators. LDR ensured that feeding only occurs during the daytime when the button is pressed, and also prevents nighttime operations. However, there are some issues, like the servo motor sometimes needs to be powered using a different source. Also, as LDR depends on Ambient light so proper threshold detection is tough . Despite all of these limitations, the experiment successfully demonstrates how to use environmental sensing, actuator control and logical conditions and using all of this, we can solve a real-time problem efficiently.

Overall, the smart pet feeder system is a strong example of basic robotics system integration using sensors, actuators, and microcontroller-based control logic and fulfils the lab objectives properly.

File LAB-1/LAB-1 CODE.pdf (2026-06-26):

## Task3 code:

#define LED_PIN 8

#define BUTTON_PIN 2

void setup() {
pinMode(LED_PIN, OUTPUT);
pinMode(BUTTON_PIN, INPUT_PULLUP); Serial.begin(9600);
}

void loop() {
int buttonState = digitalRead(BUTTON_PIN);

if (buttonState == LOW) {
digitalWrite(LED_PIN, HIGH); Serial.println("Button pressed"); }

else {
digitalWrite(LED_PIN, LOW); Serial.println("Button released"); }

delay(100);
}

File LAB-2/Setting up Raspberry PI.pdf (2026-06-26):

### (Installation of Operating System in Raspberry Pi 4)

Note: Buy a decent drive (at least 32 GB) with faster data transfer rate for smoother operation

Step 1: Flash your micro SD Card/ Pendrive to FAT-32 Format.
Step 2: Go to:- https://www.raspberrypi.com/software/ and download the Raspberry Pi Imager installer file for (Win/Mac OS).
Step 3: Install the downloaded file and open the application.

This is what the interface should look like:

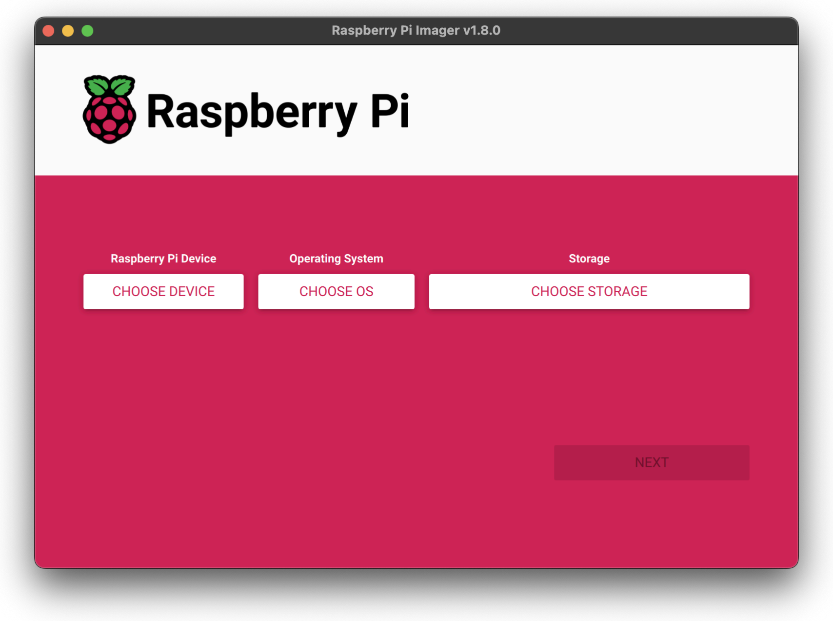
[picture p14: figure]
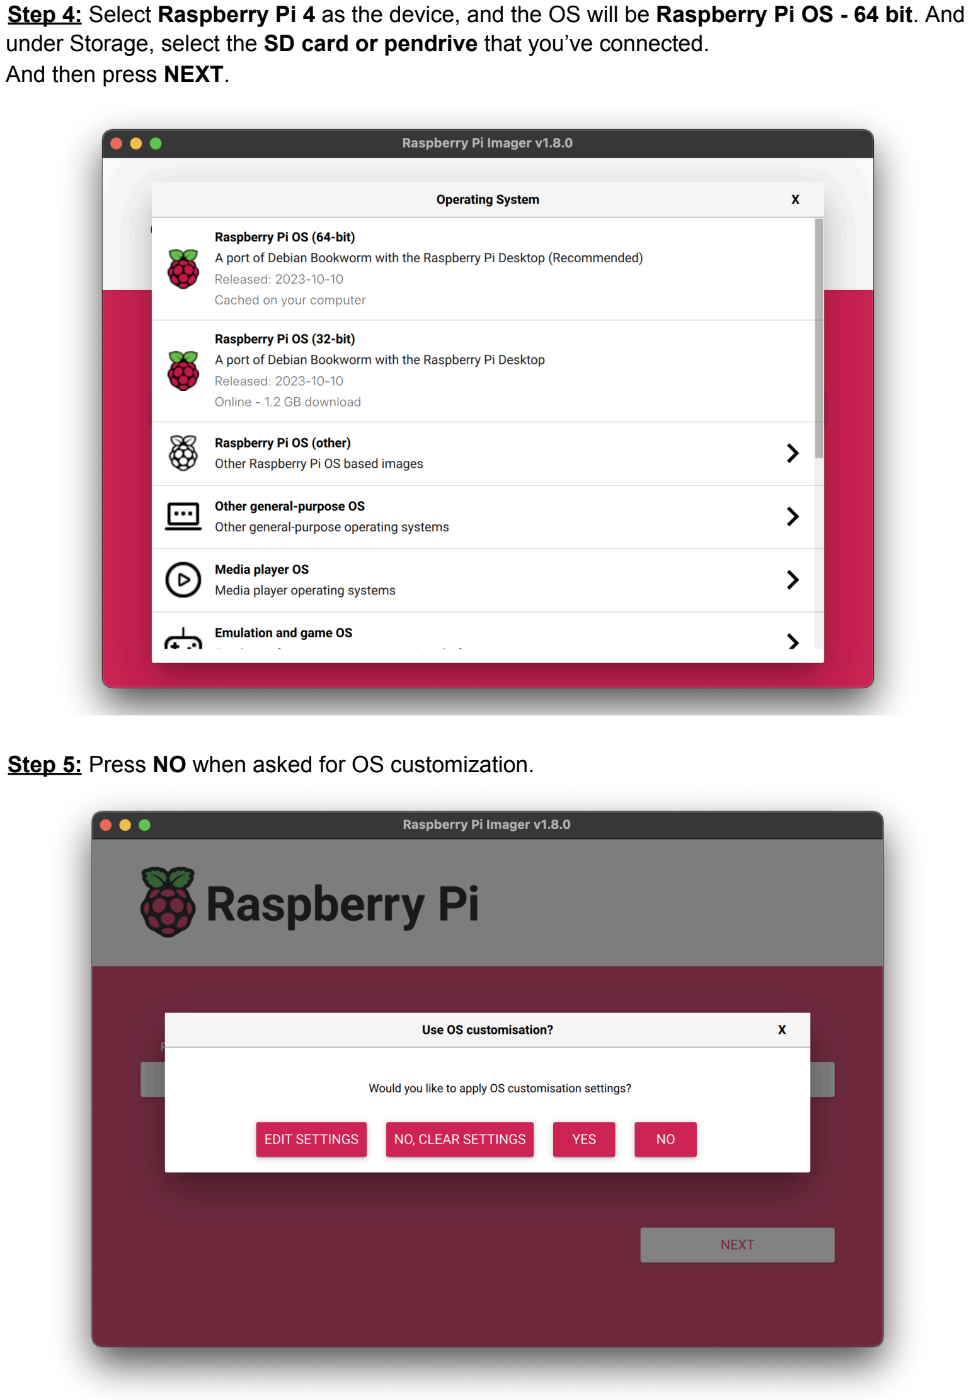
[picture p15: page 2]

Step 4: Select Raspberry Pi 4 as the device, and the OS will be Raspberry Pi OS - 64 bit. And under Storage, select the SD card or pendrive that you’ve connected.
And then press NEXT.
Step 5: Press NO when asked for OS customization.

Step 6: Insert the SD card into the card slot below or the pen drive into the USB slot in the Raspberry Pi.
Step 7: Connect the Raspberry Pi to a monitor via an HDMI connector, connect the power supply, and turn it on. The system should boot automatically, and you can operate it via a keyboard and mouse. If everything works properly, you will see the boot up screen:

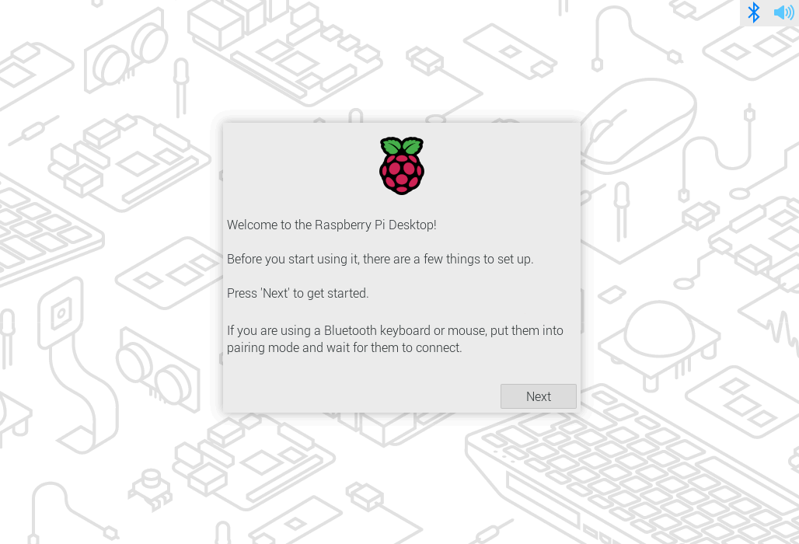
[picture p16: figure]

Step 8: Follow the instructions given below for the next steps:
- Set the Country and Timezone
- Create User (You can choose any username and password)
- Skip connecting wi-fi at this stage
- Select browser (Chromium or Firefox. Either is fine)
- Skip Update Software

Step 9: After you are done configuring the OS, the system will reboot. Once completed the interface would look like this:

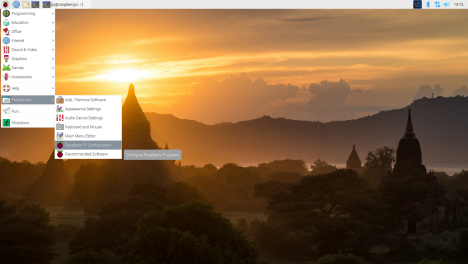
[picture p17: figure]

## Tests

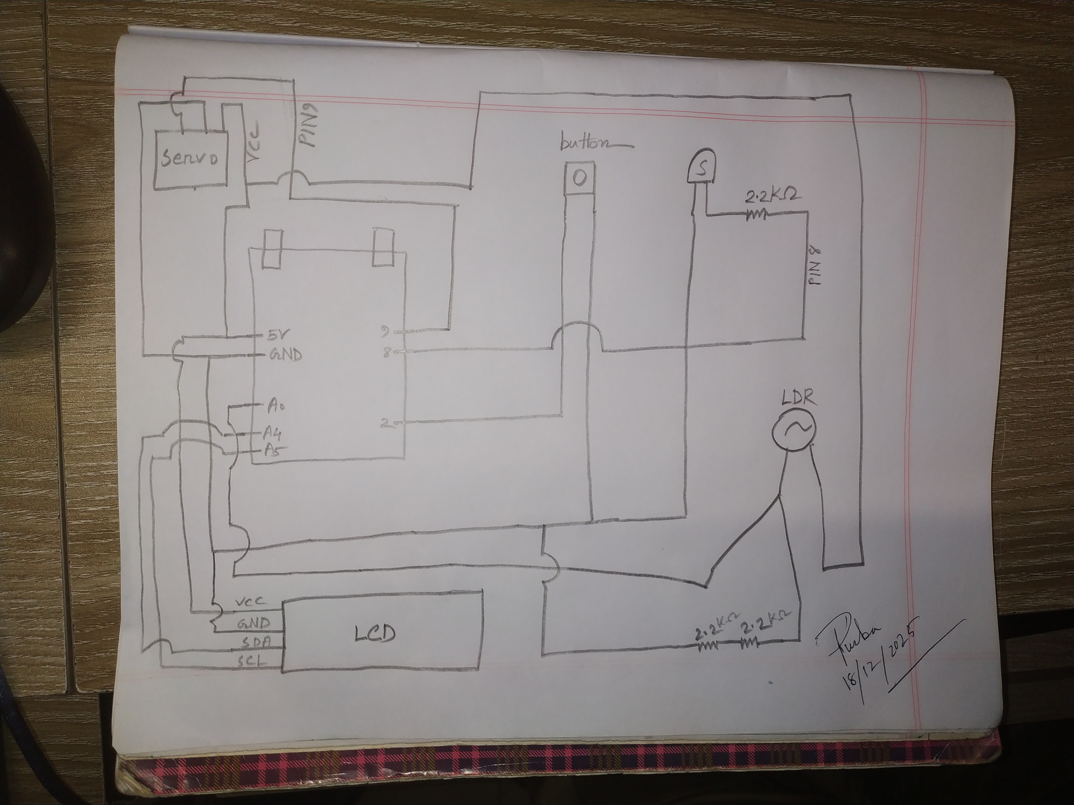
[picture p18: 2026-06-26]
LAB-Evaluation/storage emulated 0 Android data com.miui.gallery cache SecurityShare 1766052360075.jpg

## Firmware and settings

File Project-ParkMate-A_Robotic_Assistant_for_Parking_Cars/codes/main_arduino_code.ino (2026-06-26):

#include <Wire.h>
#include <LiquidCrystal_I2C.h>
#include <Servo.h>

// ---------------- LCD ----------------
LiquidCrystal_I2C lcd(0x27, 16, 2);

// ---------------- Pins (UNO) ----------------
const int TRIG_ENTRY = 2;
const int ECHO_ENTRY = 3;
const int TRIG_EXIT  = 4;
const int ECHO_EXIT  = 5;

const int IR1 = 6;
const int IR2 = 7;
const int IR3 = 8;

const int SERVO_GATE_ENTRY = 9;
const int SERVO_GATE_EXIT  = 10;

const int SERVO_CLEAN_1 = 11;
const int SERVO_CLEAN_2 = 12;
const int SERVO_CLEAN_3 = 13;

// LEDs on analog pins as digital outputs
const int LED1 = A0;
const int LED2 = A1;
const int LED3 = A2;

const int RELAY_EV = A3;

// ---------------- Servos ----------------
Servo gateEntry, gateExit;
Servo clean1, clean2, clean3;

// ---------------- System config ----------------
const int GATE_OPEN_ANGLE = 90;
const int GATE_CLOSED_ANGLE = 0;
const int GATE_TRIGGER_CM = 3;
const bool IR_ACTIVE_LOW = true;
const unsigned long CLEAN_AFTER_EMPTY_MS = 3000;
const unsigned long STATUS_SEND_PERIOD_MS = 3000;

// ---------------- State ----------------
bool slotOcc[3] = {false, false, false};
bool prevSlotOcc[3] = {false, false, false};

unsigned long slotEmptySince[3] = {0, 0, 0};
bool cleaningDoneForThisEmpty[3] = {false, false, false};

unsigned long lastStatusSendMs = 0;

// ---------------- Helpers ----------------
long readDistanceCm(int trigPin, int echoPin) {
  digitalWrite(trigPin, LOW);
  delayMicroseconds(2);
  digitalWrite(trigPin, HIGH);
  delayMicroseconds(10);
  digitalWrite(trigPin, LOW);

  long duration = pulseIn(echoPin, HIGH, 30000UL);
  if (duration == 0) return 999;
  return duration / 58;
}

bool readIR(int pin) {
  int v = digitalRead(pin);
  return IR_ACTIVE_LOW ? (v == LOW) : (v == HIGH);
}

void setGate(Servo &s, int angle) {
  s.write(angle);
}

void cleanSlot(Servo &s) {
  s.write(0);
  delay(250);
  s.write(180);
  delay(600);
  s.write(0);
  delay(250);
}

void updateLeds() {
  digitalWrite(LED1, slotOcc[0] ? LOW : HIGH);
  digitalWrite(LED2, slotOcc[1] ? LOW : HIGH);
  digitalWrite(LED3, slotOcc[2] ? LOW : HIGH);
}

void updateRelay() {
  digitalWrite(RELAY_EV, slotOcc[0] ? HIGH : LOW);
}

int availableCount() {
  int occ = slotOcc[0] + slotOcc[1] + slotOcc[2];
  return 3 - occ;
}

void updateLCD() {
  lcd.clear();
  lcd.setCursor(0,0);
  lcd.print("Avail:");
  lcd.print(availableCount());
  lcd.print("  Occ:");
  lcd.print(3 - availableCount());

  lcd.setCursor(0,1);
  lcd.print("S1:");
  lcd.print(slotOcc[0] ? "X" : "O");
  lcd.print(" S2:");
  lcd.print(slotOcc[1] ? "X" : "O");
  lcd.print(" S3:");
  lcd.print(slotOcc[2] ? "X" : "O");
}

// ---------------- SERIAL → ESP8266 ----------------
void sendStatusToESP(bool force) {
  unsigned long now = millis();
  if (!force && (now - lastStatusSendMs) < STATUS_SEND_PERIOD_MS) return;
  lastStatusSendMs = now;

  int avail = availableCount();
  int occ = 3 - avail;
  int ev = slotOcc[0] ? 1 : 0;

  Serial.print("PARK,");
  Serial.print(avail); Serial.print(",");
  Serial.print(occ);   Serial.print(",");
  Serial.print(slotOcc[0] ? 1 : 0); Serial.print(",");
  Serial.print(slotOcc[1] ? 1 : 0); Serial.print(",");
  Serial.print(slotOcc[2] ? 1 : 0); Serial.print(",");
  Serial.println(ev);
}

// ---------------- SETUP ----------------
void setup() {
  pinMode(TRIG_ENTRY, OUTPUT);
  pinMode(ECHO_ENTRY, INPUT);
  pinMode(TRIG_EXIT, OUTPUT);
  pinMode(ECHO_EXIT, INPUT);

  pinMode(IR1, INPUT);
  pinMode(IR2, INPUT);
  pinMode(IR3, INPUT);

  pinMode(LED1, OUTPUT);
  pinMode(LED2, OUTPUT);
  pinMode(LED3, OUTPUT);

  pinMode(RELAY_EV, OUTPUT);
  digitalWrite(RELAY_EV, LOW);

  // ✅ Hardware Serial (D0/D1)
  Serial.begin(9600);

  lcd.init();
  lcd.backlight();

  gateEntry.attach(SERVO_GATE_ENTRY);
  gateExit.attach(SERVO_GATE_EXIT);
  clean1.attach(SERVO_CLEAN_1);
  clean2.attach(SERVO_CLEAN_2);
  clean3.attach(SERVO_CLEAN_3);

  setGate(gateEntry, GATE_CLOSED_ANGLE);
  setGate(gateExit, GATE_CLOSED_ANGLE);

  slotOcc[0] = readIR(IR1);
  slotOcc[1] = readIR(IR2);
  slotOcc[2] = readIR(IR3);

  updateLeds();
  updateRelay();
  updateLCD();
  sendStatusToESP(true);
}

// ---------------- LOOP ----------------
void loop() {
  long dEntry = readDistanceCm(TRIG_ENTRY, ECHO_ENTRY);
  setGate(gateEntry, dEntry <= GATE_TRIGGER_CM ? GATE_OPEN_ANGLE : GATE_CLOSED_ANGLE);

  long dExit = readDistanceCm(TRIG_EXIT, ECHO_EXIT);
  setGate(gateExit, dExit <= GATE_TRIGGER_CM ? GATE_OPEN_ANGLE : GATE_CLOSED_ANGLE);

  bool newOcc[3];
  newOcc[0] = readIR(IR1);
  newOcc[1] = readIR(IR2);
  newOcc[2] = readIR(IR3);

  bool changed = false;
  unsigned long now = millis();

  for (int i = 0; i < 3; i++) {
    prevSlotOcc[i] = slotOcc[i];
    slotOcc[i] = newOcc[i];

    if (slotOcc[i] != prevSlotOcc[i]) {
      changed = true;
      if (!slotOcc[i]) {
        slotEmptySince[i] = now;
        cleaningDoneForThisEmpty[i] = false;
      } else {
        slotEmptySince[i] = 0;
        cleaningDoneForThisEmpty[i] = true;
      }
    }

    if (!slotOcc[i] && slotEmptySince[i] != 0 && !cleaningDoneForThisEmpty[i]) {
      if (now - slotEmptySince[i] >= CLEAN_AFTER_EMPTY_MS) {
        if (i == 0) cleanSlot(clean1);
        if (i == 1) cleanSlot(clean2);
        if (i == 2) cleanSlot(clean3);
        cleaningDoneForThisEmpty[i] = true;
        changed = true;
      }
    }
  }

  if (changed) {
    updateLeds();
    updateRelay();
    updateLCD();
    sendStatusToESP(true);
  } else {
    sendStatusToESP(false);
  }

  delay(50);
}
